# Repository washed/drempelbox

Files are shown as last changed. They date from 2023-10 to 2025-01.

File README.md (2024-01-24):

# drempelbox

kids friendly audio system

## Building

### Using cross

This project uses [cross](https://github.com/cross-rs/cross/) for compiling to different target architectures.
Cross requires a regular rust install via [rustup](https://rustup.rs/), docker or podman, and a Linux kernel mit binmft_misc support, see also [cross dependencies](https://github.com/cross-rs/cross/#dependencies).

Then install cross using cargo:
```bash
cargo install cross --git https://github.com/cross-rs/cross
```

To build for 64bit RaspberryPi OS (aarch64-unknown-linux-gnu), use
```bash
make build-aarch64-unknown-linux-gnu
```

To build for build-x86_64-unknown-linux-gnu, use
```bash
make build-aarch64-unknown-linux-gnu
```

Cross uses a containerized build environment to make cross compilation easy, install any
external dependencies for the build step in [Dockerfile.cross](Dockerfile.cross).
Docker [buildx](https://docs.docker.com/build/architecture/#install-buildx) is required for monitoring the build progress.

### Building directly on the host

You can also build this project directly on your host machine (for its architecture) using just cargo.
You will need to install the ALSA dev libs for your system, though (libasound2-dev on many platforms).

### Building on the RaspberryPi

***Don't do this unless you really need to! Compiling on the Zero 2W is very slow!***

To install the rust toolchain on the Zero 2W, you need to increase swap size.
From https://gist.github.com/tstellanova/0a6d8a70acc58a0d5be13ebaa7c935d4

```bash
sudo dphys-swapfile swapoff
sudo nano /etc/dphys-swapfile
```

Change `CONF_SWAPSIZE=100` to `CONF_SWAPSIZE=512` (or 1024)

```bash
sudo dphys-swapfile setup
sudo dphys-swapfile swapon
sudo reboot
```

Change to any swap size you feel appropriate for your needs.

## Running on RPi Zero 2W

Assuming a 64 bit RaspberryPI OS lite, install these packages to enable audio support:
- pipewire
- pipewire-alsa

Enable SPI for NFC ready support (using the raspi-config tool, for example).

Modify `/boot/firmware/config.txt`, adding this line at the end:
```
dtoverlay=gpio-poweroff,gpiopin=4,active_delay_ms=5000,inactive_delay_ms=1000,active_low=1
```
This enables the Pi to keep itself powered during normal operation
and switch itself off after poweroff. See the [schematic](#schematic) for details.

Create the service user and its group:
`sudo adduser --system --no-create-home --group drempelbox --uid 1337`

Add the user to these system groups to give it the necessary permissions:
```bash
sudo usermod -a -G gpio drempelbox
sudo usermod -a -G audio drempelbox
sudo usermod -a -G spi drempelbox
```

Create a polkit rule to allow the user to shutdown the system.
Create the file `/etc/polkit-1/rules.d/40-allow-shutdown.rules` and add these contents:
```
/* Allow members of the drempelbox group to shutdown without authentication */
polkit.addRule(function(action, subject) {
   if ( ( action.id == "org.freedesktop.login1.power-off" ||
          action.id == "org.freedesktop.login1.power-off-multiple-sessions"
        ) && subject.isInGroup("drempelbox") ) {
     polkit.log("Powering Off permitted for subject" + subject)
     return polkit.Result.YES;
   }
});
```

Restart the system or the polkit service for the changes to take effect:
```bash
systemctl restart polkit.service
```

## Hardware

Rough block diagram of system components:
```mermaid
classDiagram
    direction BT
    USB_PD_Decoy o-- Powerbank : USB A to USB C
    StepDownReg o-- USB_PD_Decoy : 12V
    5VFilter <|-- StepDownReg
    RPi <|-- 5VFilter : 5V micro USB
    RPi <|--|> NFC_Module : 5V, SPI
    USB_Soundcard *-- RPi : USB
    Amplifier <|-- USB_Soundcard : 3.5mm TRS
    Amplifier  o-- USB_PD_Decoy : 12V
    Speakers <|-- Amplifier

    class NFC_Module {
    }
    class RPi["RPi Zero 2W"] {
    }
    class USB_Soundcard["USB Soundcard"] {
    }
    class Powerbank{
        USB PD
        SoC Display
        USB C in/out
        USB Micro in
        USB A out
        charge()
        discharge()
    }
    class USB_PD_Decoy["USB PD Decoy"]{
        12V
    }
    class StepDownReg["5V DC/DC Buck"]{
        12V -> 5V
    }
    class 5VFilter["5V Filter"]
    class Amplifier{
    }
    class Speakers{
    }
```

### Schematic

KiCAD schematic

## Software

```mermaid
flowchart
    subgraph NTAG
        present{token presence changed?} -- no --> delay((delay)) --> present
        present -- added --> read[read token]
        present -- removed --> sendreq_ntag_stop[send player stop  request]
        read --> parse --> parse_ok
        parse_ok{is url?} -- yes --> sendreq_ntag_play[send player play request]
    end

    subgraph Player
        sendreq_ntag_stop --> stop{{stop all playback}}
        sendreq_ntag_play --> type{file or https}
        type -- file --> playfile{{stop spotify, play file}}
        type -- https --> isspotify{starts with 'open.spotify.com'?}
        isspotify -- no --> error
        isspotify -- yes --> playspotify{{stop file, play spotify}}
    end

    subgraph HTTP
        post_play[POST to play endpoint] --> query{has url query param?}
        query -- yes --> type
    end

```

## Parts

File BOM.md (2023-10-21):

# Bill of Materials

This list contains only the bigger BOM items as the rest (cables etc.) is very much in flux and will change a lot between versions.

| Item | Cost pp | Count | | Links |
| --- | --- | ----- | --- | --- |
| RPi Zero 2W | 20,00 | 1 | | [rasppishop](https://www.rasppishop.de/Raspberry-Pi-Zero-2-W) [berrybase](https://www.berrybase.de/raspberry-pi-zero-2-w) [welectron](https://www.welectron.com/Raspberry-Pi-Zero-2-W) |
| MicroSD card | ~ | 1 | | |
| micro USB otg -> USB A adapter | ~ | 1 | | |
| 40 pin RPi header | ~ | 1 | | |
| MFRC522 Module | 3,50 | 2 | | [amazon](https://amzn.eu/d/f9zHGjk) |
| USB soundcard | 7,99 | 1 | | [amazon](https://amzn.eu/d/9gCCpZK) |
| amplifier | 15,95 | 1 | | [soundimports](https://www.soundimports.eu/de/sure-electronics-aa-ab32231.html) |
| speaker chassis pair | 29,90 | 1 | | [soundimports](https://www.soundimports.eu/de/dayton-audio-dma45-4.html) |
| USB PD decoy | 4,35 | 2 | | [amazon](https://amzn.eu/d/6iVZGkV) |
| 5V step down | 6,95 | 2 | We _might_ need a bigger one | [pololu](https://www.pololu.com/product/2107) |
| Power bank | 16,99 | 2 | | [amazon](https://amzn.eu/d/ijY3aWm) |
| NFC tags | 0,33 | 40 | Anything [NTAG215](https://www.nxp.com/products/rfid-nfc/nfc-hf/ntag-for-tags-and-labels/ntag-213-215-216-nfc-forum-type-2-tag-compliant-ic-with-144-504-888-bytes-user-memory:NTAG213_2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) compatible should work | [amazon](https://amzn.eu/d/1htxMxP) |

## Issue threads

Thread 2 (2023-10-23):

Noisy Audio

washed, 2023-10-23:
The current setup emits a lot of audible noise from the speakers when both the RPi and the amp are powered from the same power source. Observed first in the prototype using the Pololu 5V DCDC converter for powering the Pi. The following lists the steps performed to debug this issue thus far.

* Assumed the noise originates from the DCDC converter
  * inserted LC filter between DCDC converter and RPi => **no change**
  *  powered pi from 5V rail of a clean lab power supply => **no change**
* Disconnected TRS audio cable between RPi and amp => **no noise (but obviously no audio, either)**
* Powering the RPi from a separate USB power supply, grounds probably disconnected (needs to be verified) => **clean audio!**

The last point indicates some issue with ground loops.

Next things to try:
* create star ground closer to the sound card/amp
* use shorter cables
* split grounds between sound card and amp
* check for ground loops in general

washed, 2023-10-28:
Mostly fixed by using the differential inputs (in fake diff mode because of the single end source). Some background noise remains and what is probably current ripple when using the 5V DCDC converter. The latter should still be addressed for the MVP imo.

tmh-alex, 2023-11-11:
There is the faintest background noise in my setup as well. I think it's really coming from the amp and I'm a bit 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.
Would've expected better performance from such a circuit.

But let's stay grounded (pun intended), it's really not a problem at all.

washed, 2023-11-12:
Yes I agree. Maybe after the MVP we could look for a lower power, lower noise alternative.

Meanwhile, give #16 a spin for a software approach to minimize experienced noise ;)

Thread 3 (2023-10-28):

Power on NFC

tmh-alex, 2023-10-28:
# What
If the Drempelbox is in standby, placing a tag on the reader wakes it up and starts playing right away.

# Why
Improved user experience with the user base "babies" in mind.

# Open questions
* How to poll the reader while in standby?
* What does standby mean? Raspi in low-energy state? Raspi turned off and power supply reacting on plugin signal?

washed, 2023-10-29:
This is super interesting.
Raspis don't really have low power states (like in ACPI compliant systems, for example). Afaik there is the `halt` state which shuts the OS down but keeps the bootcode in cache. The OS can be booted from this state via GPIO input. That might be one option. It will however be a mostly regular linux boot. Stuff like suspend to RAM does not exist for the Pi afaik.
A few options i could think of:
* keep the pi running, maybe try to shutdown cores or as much peripherals as possible, also keep the amp off and define this as our standby. NFC and the app (or a part of the app?) could keep running and watch the NFC reader.
* use a secondary MCU, also connected to the NFC reader, polling it regularly if the Pi is off. When it detects the presence of a token, boot the Pi and relinquish the SPI bus (tristate the pins). This could give us a bit more advanced power management stuff in general. Perhaps it will turn it, we need an extra MCU anyway. I hope not.
* in addition to the NFC reader, place a reed-relay, a magnetic or capacitive proximity sensor, or similar, where the presence of a figurine would trigger it, this could boot the Pi from aforementioned halt or off state

washed, 2023-10-30:
The simplest way would probably be the reed relay, which comes with the added benefit that it does not require power. It would mean we need a magnet in every figurine instead of in the base. Sure, we could also use an integrated, low force push button on the reader side, but to me this somehow breaks the very "non-mechanical" feel of the nfc interface. What do you think?

washed, 2023-10-31:
Reed relais were on sale at Reichelt and i needed some small bits and pieces anyway. I guess this is something we can start to work on when the MVP is done/close.

tmh-alex, 2023-11-01:
Certainly not an MVP thing. I don't like having mechanical components (other than the chassis, obviously) either, so let's focus on your [first two bullets](https://github.com/washed/drempelbox/issues/3#issuecomment-1784088492).

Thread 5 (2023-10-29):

Power on/off

washed, 2023-10-29:
After we have a possible, to be tested, solution in #11, we collect some additional stuff for discussion etc here. This thereby obsoletes #7.

washed, 2023-10-31:
See #11 for a possible solution.

washed, 2023-11-02:
I did some measurements to see if we have an issue here as described in https://github.com/washed/drempelbox/pull/11#pullrequestreview-1708477097.

### off
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
CH1: AMP_SD
CH2: AMP_SD_PI

### on
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
CH1: AMP_SD
CH2: AMP_SD_PI

### regular boot
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
CH1: AMP_SD
CH2: AMP_SD_PI
interesting blip there, maybe from GPIO configuration

### being rude and pulling the USB plug at the power bank
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
CH1: AMP_SD
CH2: AMP_SD_PI

### power bank turns on (pressing the button)
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
CH1: AMP_SD
CH2: VDD (12V rail)
note that we only see the ramp up from 5V to 12V here. Might need another capture, timing could also be interesting here. Very clean slope, though.

### power bank shuts off due to low current condition
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
CH1: AMP_SD
CH2: VDD (12V rail)

tmh-alex, 2023-11-11:
This all looks very promising as already mentioned on Signal, and if I'm not mistaken, your efforts already bore fruits to turn the box reliably off.
Then power-on part, on the other hand... :thinking: We have all sorts of ideas after the MVP, but a simple solution to start with?

washed, 2023-11-12:
The current circuit covers power on, in theory. I need to try it in practice. The idea was to rewire the button so it starts the power bank and the 5V supply. Shutdown via the same button should also be possible with another GPIO and some diodes.

washed, 2024-01-10:
Newest implementation in #15 should address all remaining issues we discovered in here.

Closed 2024-01-10.

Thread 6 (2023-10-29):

Assess power comsumption

washed, 2023-10-29:
I think we should have a rough idea which subsystems use what power in a few typical situations.
This would help us to optimize at the right place if we need to.

tmh-alex, 2023-10-29:
Setup
* raspi supplied by battery (optimistic **37 Wh** capacity)
* USB audio interface connected
* no user processes except ssh running (other than OS)

Results
* Battery lost **23 %** charge after **9.5 h** uptime
* Roughly **180 mA** average consumption

tmh-alex, 2023-10-29:
Good source for power saving possibilities on the raspi: https://raspberrypi.stackexchange.com/a/133854
The user also linked [this](https://learn.pi-supply.com/make/how-to-save-power-on-your-raspberry-pi/), [this](https://forums.raspberrypi.com/viewtopic.php?t=257144) and [this](https://blues.io/blog/tips-tricks-optimizing-raspberry-pi-power/) quite useful pages. Also proposed addon boards such as as [Sleepy Pi](https://spellfoundry.com/product/sleepy-pi/) and [Witty](https://www.uugear.com/product/witty-pi-3-realtime-clock-and-power-management-for-raspberry-pi/).

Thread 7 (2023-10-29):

Amp shutdown control

washed, 2023-10-29:
Some NPN BJT and a few resistors should do it, i think?
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

tmh-alex, 2023-10-29:
Works. Guess you could crank up R1, R2, and R5 by a magnitude of ten. Should still be robust enough against noise and reduced power consumption. I wonder if R2 is needed at all (defeats the floating property, doesn't it)?

washed, 2023-10-29:
Good points, thanks! That looks good as well:
* removed R2
* R1 to 10k
* R5 to 100k

Low level seems to be around 80mV; should be totally fine for a TTL input.
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

tmh-alex, 2023-10-29:
Waaait, aren't we overlooking the obvious? Is R5 even needed, either? According to the datasheet the base cutoff current is 50 nA, putting the upper limit of R1 to 52 MOhm. With 1 Mohm we'll surely be on the safe side with a base current of 2.6 mA. We can afford that :)

washed, 2023-10-29:
I have to admit i am super rusty (ha!) on discrete stuff. It seems fine without R5 and an R1 up to ~20k from some quick sim.

tmh-alex, 2023-10-29:
No worries, I learned and used this stuff at some point and I had to look at the diagram three times.

washed, 2023-10-29:
Used a BC547C (first NPN i found in a bag^) and a 100k between base and gpio. works a treat. One potential (pun intended) issue: we need to tie two previously separated grounds together. We'll need to see if this has any adverse effects; the schematic assumed both grounds are already the same net.

tmh-alex, 2023-10-29:
If that's a problem, try a 0.33 uF capacitor between the transistor base and the raspi ground. This should make a first order filter with the cutoff frequency at around 25 Hz (assuming R1=20 kOhm)

washed, 2023-10-29:
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

Much complex

washed, 2023-10-30:
Software side is implemented by this:
https://github.com/washed/drempelbox/commit/2e209eeeb605e9b5bdb4f3ad1ef7510ee3e0d448
we'll need to decide on when to switch on/off at some point. But now it is possible to do so :)

washed, 2023-10-31:
See #11 for an updated version of this

washed, 2023-11-02:
Happy with this after initial testing. Also see #11, #5.

Closed 2023-11-02.

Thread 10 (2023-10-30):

Cannot open ecad pdf and svg

tmh-alex, 2023-10-30:
Ecad [pdf](ecad/schematic.pdf) and [svg](ecad/schematic.svg) won't render/open on both my machine as well as in the repo landing page.

washed, 2023-10-30:
There where some screwed up versions initially. I force pushed over them, but i believe they stuck

washed, 2023-10-31:
@tmh-alex is this still broken for you?

tmh-alex, 2023-11-01:
It seems to be a Firefox problem, can open and download the files with Chromium no prob. First I thought it was thanks to the total Chrome dominance, but then I remembered that you're using FF, too...

washed, 2023-11-02:
I'm using chromium for private stuff on my laptop. I'll try with Firefox to see if I can reproduce this.

washed, 2023-11-02:
Works on Firefox just fine for me. Using Firefox 119.

tmh-alex, 2023-11-11:
Nargh, I missed to whitelist one domain in NoScript. Problem solved.

Closed 2023-11-11.

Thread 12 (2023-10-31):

Repo structure

washed, 2023-10-31:
We now have software, documentation, schematics etc in this repo.
Do we want to restructure the repo a bit to make it easier to find stuff?
A first good step might be to put all of the software pieces into their own subfolder?

Something like:
* root
  * ecad
  * app
  * mcad

tmh-alex, 2023-11-01:
The project is small enough that I have no feelings whatsoever about it's current structure. But it's probably a good idea in the long run!

To expand your proposal a bit, is that where you're heading?
* /
  * app/
    * audio/
    * ...
    * src/
    * Docker stuff
    * Makefile
    * Rust stuff
    * ...
  * ecad/
  * mcad/

washed, 2023-11-01:
zeah something like that. But we can also leave it like it is for now

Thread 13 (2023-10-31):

Read power bank SOC

washed, 2023-10-31:
Maybe somewhat unnecessary, but i was thinking if we should read the power banks soc display to get this state into our application. This would allow us to do a few interesting things like
* warn when we are running out battery (playing a sound or something)
* performing a clean shutdown before the battery dies
* just do it because it's fancy

"worst case" would be to use a shift register to get the led states.

tmh-alex, 2023-11-01:
[chimes, Majel Barrett's voice] Warning, core at 5 %. Emergency shutdown imminent.

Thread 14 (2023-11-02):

Volume Control UI

washed, 2023-11-02:
We already decided on using push buttons for controlling volume. One for volume up, one for volume down. We should start to think about how we want to integrate this into our case design (which we also still need to do).
Any bright ideas?

tmh-alex, 2023-11-11:
Following your philosophy of minimizing moving parts, how about capacitive touch sensors? E.g., https://www.adafruit.com/product/1362. We could use something as simple as screwheads as the touch interface (though i'd prefer something prettier).

washed, 2023-11-12:
I also thought about touch, it would be elegant for sure. Maybe some nicely finished and inset stainless steel bolts. However, i am unsure how well touch works for little kids. I could imagine that haptic feedback might be really useful. What do you think?

tmh-alex, 2023-11-12:
Have you got an old rumble gamepad lying around perhaps? Best of both worlds 8)

But seriously, you've got a point there. Some very sturdy rubber some would be child-friendly?

washed, 2023-11-12:
I was thinking about vibration as well... might be interesting post MVP. I also briefly thought about mild electric shocks, but i somehow think this won't fly :imp:
Originally i thought about a regular super cheap push button with some wooden actuator on top that's held in place with some tape or a rubber gasket.

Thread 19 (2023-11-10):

librespot channel closed error

tmh-alex, 2023-11-10:
Got this spurious error:
```
Nov 10 23:40:41 toniblaster drempelbox[1365]: 2023-11-10T22:40:41.859773Z  INFO drempelbox::player: playing spotify from url log_url="https://open.spotify.com/track/4abJbqX8C8CQTXHZxEbJZz?si=f04b62b8e85c4bf1"
Nov 10 23:40:41 toniblaster drempelbox[1365]: Playing...
Nov 10 23:40:41 toniblaster drempelbox[1365]: 2023-11-10T22:40:41.859864Z ERROR librespot_playback::player: Player Commands Error: channel closed
Nov 10 23:40:41 toniblaster drempelbox[1365]: 2023-11-10T22:40:41.864665Z DEBUG hyper::proto::h1::conn: read eof
Nov 10 23:40:47 toniblaster drempelbox[1365]: 2023-11-10T22:40:47.289095Z DEBUG hyper::proto::h1::io: parsed 3 headers
Nov 10 23:40:47 toniblaster drempelbox[1365]: 2023-11-10T22:40:47.289181Z DEBUG hyper::proto::h1::conn: incoming body is empty
Nov 10 23:40:47 toniblaster drempelbox[1365]: 2023-11-10T22:40:47.289273Z  INFO drempelbox::server: Got stop request
Nov 10 23:40:47 toniblaster drempelbox[1365]: 2023-11-10T22:40:47.289313Z  INFO drempelbox::server: submitted stop request
Nov 10 23:40:47 toniblaster drempelbox[1365]: 2023-11-10T22:40:47.289455Z DEBUG hyper::proto::h1::io: flushed 75 bytes
Nov 10 23:40:47 toniblaster drempelbox[1365]: 2023-11-10T22:40:47.289497Z  INFO drempelbox::player: received stop request
Nov 10 23:40:47 toniblaster drempelbox[1365]: 2023-11-10T22:40:47.289542Z  INFO drempelbox::spotify_player: stopping spotify
Nov 10 23:40:47 toniblaster drempelbox[1365]: 2023-11-10T22:40:47.289586Z ERROR librespot_playback::player: Player Commands Error: channel closed
Nov 10 23:40:47 toniblaster drempelbox[1365]: 2023-11-10T22:40:47.297705Z DEBUG hyper::proto::h1::conn: read eof
```
Couldn't repeat it. The steps that came before this error as far as I can remember:
1. `make track`
2. `make stop`
3. A few more times 1 and 2
4. `make volume_up` a couple of times while player was stopped

washed, 2023-11-11:
Looks like the entire player task died. We will need some sort of watchdog thingy for all of those long running tasks anyhow. I'll think about it. Same for the file player to make sure the sink is still running, the web server is still running etc...

I think the hyper logs are unrelated.

washed, 2023-11-11:
Ah, do you have logs before the ones you posted? Ideally from the start of the app until you saw the failure? Even the first play request in the logs you posted seems to have failed.

tmh-alex, 2023-11-11:
I'm starting to like journalctl. It's even possible to get the logs for a particular boot session. Here're the complete logs for the drempelbox process, tell me if you need all the logs (including kernel messages perhaps?).

washed, 2023-11-12:
Awesome, thanks! Looks to me like the spotify player crashed somewhere inside librespot and took the bigger player thread down with it:
```
Nov 10 23:39:57 toniblaster drempelbox[1365]: 2023-11-10T22:39:57.022170Z  INFO drempelbox::server: Got URL request url="https://open.spotify.com/track/4abJbqX8C8CQTXHZxEbJZz?si=f04b62b8e85c4bf1"
Nov 10 23:39:57 toniblaster drempelbox[1365]: 2023-11-10T22:39:57.022264Z  INFO drempelbox::server: submitted URL request
Nov 10 23:39:57 toniblaster drempelbox[1365]: 2023-11-10T22:39:57.022463Z  INFO drempelbox::player: received URL player request log_url="https://open.spotify.com/track/4abJbqX8C8CQTXHZxEbJZz?si=f04b62b8e85c4bf1"
Nov 10 23:39:57 toniblaster drempelbox[1365]: 2023-11-10T22:39:57.022507Z  INFO drempelbox::player: playing spotify from url log_url="https://open.spotify.com/track/4abJbqX8C8CQTXHZxEbJZz?si=f04b62b8e85c4bf1"
Nov 10 23:39:57 toniblaster drempelbox[1365]: Playing...
Nov 10 23:39:57 toniblaster drempelbox[1365]: 2023-11-10T22:39:57.022675Z DEBUG librespot_playback::player: command=Load(SpotifyId { id: 181874502310399482585459847615985601637, audio_type: Track }, true, 0)
Nov 10 23:39:57 toniblaster drempelbox[1365]: 2023-11-10T22:39:57.028615Z DEBUG hyper::proto::h1::conn: read eof
Nov 10 23:39:57 toniblaster drempelbox[1365]: 2023-11-10T22:39:57.051347Z DEBUG librespot_core::session: Invalidating session[0]
Nov 10 23:39:57 toniblaster drempelbox[1365]: 2023-11-10T22:39:57.051520Z ERROR librespot_playback::player: Unable to load audio item: MercuryError
Nov 10 23:39:57 toniblaster drempelbox[1365]: 2023-11-10T22:39:57.051954Z ERROR librespot_playback::player: Unable to load audio item: MercuryError
Nov 10 23:39:57 toniblaster drempelbox[1365]: 2023-11-10T22:39:57.052092Z  WARN librespot_playback::player: Skipping to next track, unable to load track <SpotifyId { id: 181874502310399482585459847615985601637, audio_type: Track }>: ()
Nov 10 23:39:57 toniblaster drempelbox[1365]: 2023-11-10T22:39:57.052181Z DEBUG librespot_playback::player: drop PlayerInternal[0]
Nov 10 23:39:57 toniblaster drempelbox[1365]: 2023-11-10T22:39:57.052258Z  INFO drempelbox::spotify_player: EndOfTrack!
Nov 10 23:39:57 toniblaster drempelbox[1365]: 2023-11-10T22:39:57.052461Z DEBUG librespot_core::session: drop Dispatch
Nov 10 23:39:57 toniblaster drempelbox[1365]: 2023-11-10T22:39:57.052622Z ERROR librespot_core::session: Connection reset by peer (os error 104)
Nov 10 23:39:57 toniblaster drempelbox[1365]: 2023-11-10T22:39:57.059097Z DEBUG librespot_playback::player: PlayerInternal thread finished.
Nov 10 23:40:01 toniblaster drempelbox[1365]: 2023-11-10T22:40:01.002751Z  INFO drempelbox::server: Got stop request
Nov 10 23:40:01 toniblaster drempelbox[1365]: 2023-11-10T22:40:01.002791Z  INFO drempelbox::server: submitted stop request
Nov 10 23:40:01 toniblaster drempelbox[1365]: 2023-11-10T22:40:01.003253Z  INFO drempelbox::player: received stop request
Nov 10 23:40:01 toniblaster drempelbox[1365]: 2023-11-10T22:40:01.003294Z  INFO drempelbox::spotify_player: stopping spotify
Nov 10 23:40:01 toniblaster drempelbox[1365]: 2023-11-10T22:40:01.003329Z ERROR librespot_playback::player: Player Commands Error: channel closed
```

Might just have been a network glitch, this line points me to that idea:
`Nov 10 23:39:57 toniblaster drempelbox[1365]: 2023-11-10T22:39:57.052622Z ERROR librespot_core::session: Connection reset by peer (os error 104)`

We should probably be more resilient about underlying pieces crashing and restart them if necessary. If you have an idea to repro this easily, we could start working and testing a fix/improvement.

washed, 2023-11-12:
Looking at it more closely, our tasks where running just fine, but the librespot internal player died.

washed, 2024-01-12:
From playing with the service file I think i now know what happened here. When you saw this, we still had a broken service definition and the service started before all the dependencies where up, specifically the actually executing user service and the sound device. I have seen the exact same behavior when i was executing the service with the new drempelbox user, but hadn't adjusted the `Required` and `After` statements. So I'd like to park this as "probably fixed" for now. If it comes up again, we can revisit!

tmh-alex, 2025-02-02:
Didn't observe that issue anymore, either. Let's close it?

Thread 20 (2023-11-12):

Dedicated drempelbox user

washed, 2023-11-12:
This is a follow-up issue from #18.

We currently run the service as whatever user is being used for ssh'ing into the Pi and registering the service.
It might be helpful to set up a dedicated user and perhaps a group along with it to have for the application with just the permissions it needs and nothing more.

For development and even a bit beyond, the current solution is probably ok.

tmh-alex, 2024-01-08:
Agreed.

washed, 2024-01-10:
Implemented by #15

Closed 2024-01-10.

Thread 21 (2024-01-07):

Use volume buttons for skipping tracks

tmh-alex, 2024-01-07:
Since we don't (yet) have an acceleration sensor like the Tonibox, we could use the volume buttons to skip through tracks. Short press louder/quieter, long press skip forward/backward.

I'd like to take that as an opportunity to finally code some Rust.

washed, 2024-01-07:
Sounds great! Do you wanna do the basic volume button implementation as well?

Hint: we are using rppal for GPIOs

tmh-alex, 2024-01-08:
Sure! Created #22 to cover the task.

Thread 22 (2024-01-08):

Volume button support

tmh-alex, 2024-01-08:
We decided on NO hardware volume buttons that now need support.

Just like #21, I'd like to take this task to code get into Rust coding.

washed, 2024-01-08:
Took me a second to parse "normally open" correctly :)

tmh-alex, 2024-01-08:
Took me a second to parse what you mean and then it was so blatantly obvious, haha

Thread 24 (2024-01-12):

Use interrupts for reading GPIOs

washed, 2024-01-12:
Currently we are using simple polling to get the status of input pins (Pi shutdown only, but volume control will also need to read inputs). Unless it's terribly hard to do so, it would be really nice to use interrupts to read inputs! It would improve reaction time and safe on CPU time as well. Also, I like interrupts.

tmh-alex, 2024-01-16:
I like interrupts, too.

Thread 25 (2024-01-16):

Multi-box support

tmh-alex, 2024-01-16:
When two or more Drempelboxes are present in the same network, all should play simultaneously from the same (cloud) source. The latest Drempel put on any box' sensor determines the stream for all boxes.

Optional: Roon support.

washed, 2024-01-16:
Oof, sub millisecond sync with a regular Linux machine? Not saying it's impossible, but sure ain't easy.

washed, 2024-01-17:
I'm wondering if we can get away with synchronizing chunks of audio with timestamps and making sure our system times are synched _well enough_ (TBD). This would also allow a lagging box to catch up.

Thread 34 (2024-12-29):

Current state of affairs on my end

tmh-alex, 2024-12-29:
# The good
* Built up the whole circuit according to our schematic
* Added an LED as a status light to my board (changes to the schematic yet to come)
* Keepalive works fine at the press of the single-push-double-throw (SPDT)  button
* Supply switches gently off after calling `sudo shutdown now`
* Service file runs, can see continuous debug statements from the program

# The bad
* Circuit not powering off at the push of the SPDT button
* ~~`make track` etc. not working, says "could not connect to server" despite `CURL_TEST_HOST_PORT` having (I believe) the right hostname/IP and port (default 3000)~~
  * This was apparently due to Spotify stalling a couple of setup steps like port binding. Once I connected to the Drempelbox instance from my Android Spotify everything worked.
* I should make myself more familiar with what's already implemented:
  * ~~Amp circuit currently not coming alive (should this happen only when starting a new track?)~~
    * Ground connection was missing.
  * State of the shutdown functionality

# The ugly
* :exclamation: NEW: Still noisy as hell :sob:
* The assembly with all its wires connected via pinheads and some loose components is rather brittle, it won't survive long in the hands of a toddler
  * I broke one of the volume buttons in the meanwhile
* Also, everything is really cramped, making it really difficult to find errors and not causing new ones by accident in the process. I'm really fond of your idea for designing a proper PCB...

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

# The silver lining
* We're like ~~98~~ 95 % there, the remaining ~~two~~ five might be a hassle but aren't impossible! :muscle:

tmh-alex, 2025-01-05:
I think I know why my raspi seemingly died a few times in the past and it had to be set up from scratch again. It ran out of memory due to RaspiOS' default logging setting `auto`, which writes all logs including every stupid debug statement to disk. Set it to `volatile` now, let's see what happens.

tmh-alex, 2025-01-06:
Box works now except for shutdown on the push of the SPDT button. But it's noisy as hell... I thiiink it's the line between the audio adapter and the amp

tmh-alex, 2025-01-07:
Did some more investigations today.

### Noise issue
* Confirmed a previous observation from last year just to be sure: No audible noise on the USB adapter output, tried with headphones → adapter not to blame.
* Pulled the audio cable out and made sure I don't have loops around supply lines etc. Noise level is now back to the level of my original experimental setup. Shielding the cable with grounded aluminium foil didn't bring any change → Ground loop. I wonder if the digital GND is really separate or I accidentally short-circuited it again.

### Other
* Shutdown not working: Probably due to a mistake in the layout because I checked both SPDT button terminal pairs positively for their functionality.
* Amp not shutting down after stopping a song: Also just a layout mistake. I manually connected the amp's SD pin to GND, it went dead silent.
* NEW: USB-C extension cord between battery and terminal on the outside of the box is polarized (I now learned that these things are not part of the USB-C spec), orientation of the charging cable matters as a consequence.

washed, 2025-01-08:
Okay there's a lot in this single issue^^.

- Does the shutdown work when you manually pull the input to ground?
  - TBH, i don't 100% remember the state of this feature. I know there was still something i wasn't happy about wrt systemd integration
- About the USB-C extension: yes they aren't part of the spec, but if they are just dumb extensions and have all pins connected it should work in both orientations (for simple use cases). But I guess you are saying our extension only connects one half of pins?
- What are the 4 inductors (?) doing on your board?

washed, 2025-01-08:
Oh also about shutdown: did you create the polkit rules as outlined in the readme?

tmh-alex, 2025-01-08:
Thanks for the response Marc!

* Single issue: Was meant as a summary to both you and me, otherwise, I forget what part to take a look at next...
* Shutdown: Yes, it does shut down properly when manually connected to ground.
* USB-C extension and orientation: I thought it was just a dumb cable, but there seems to be more to it. I have the same issue with my laptop docking station and the extension cord I'm using there. Need to read up on the C spec, pin layout, pulldown resistors for communicating orientation, and whatnot.
* Inductor array: One inductor is 330 uH, needed a couple to get close to the design value of 1.5 mH. Probably wouldn't make a difference anyway, but I had both the parts and the space.
* Polkit rule: Yes, even added my own user to it so I can test easily if shutdown works without being root.

washed, 2025-01-08:
Are you sure the button you are using has two isolated contactors?

washed, 2025-01-09:
OR -> the button in fact doesn't have isolated contactors and thus couples the two grounds directly.

tmh-alex, 2025-01-10:
I don't have much choice in parts, I got three bags of assorted stuff for resistors, inductors and capacitors from which I have to assemble the desired values.

As for the button, I'll check the grounds. But in all likelihood, I made a mistake in the layout as I did with the amp supply. :zany_face:

tmh-alex, 2025-01-12:
Dis- and reassembled the box to day to do some investigations:
* Shutdown: Works now, it was indeed a missing ground connection as suspected.
* Digital ground: Completely behind the inductors, proved by removing one of the four series inductances to break the circuit.
* Noise: Still there, bending and moving the wires has influence on noise levels.
Box is up and running again. With amp shutdown when the stop signal is sent it won't bother me for now. Btw, the box idles with the amp powered and the amp shutdown pin floating. Don't know yet if this is expected behaviour.

tmh-alex, 2025-01-13:
I forgot to have a look at the shutdown circuit yesterday. Good news, it's also fixed now! I just had the base of transitor Q1 (the one that pulls AMP_SD to ground or leaves it floating) permanently connected to ground. One of the many issue resulting from my sloppiness when working prototyping boards that have their lanes all the way from one end to the other...

The noise, however, is still there when playing tracks. I will close this issue and open a new one one with a more limited scope. ;-)

tmh-alex, 2025-01-16:
Noise gone thanks to @washed's simple 1.5 mH coil in place of my storage chokes. 💪 Fwiw, the simple coil has about 10 Ohms resistance.

Closed 2025-01-16.

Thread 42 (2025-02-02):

Observations after ten days with the kid

tmh-alex, 2025-02-02:
Just fyi @washed

# User Experience

## Good
* It exists at all and the kid has a new toy that it likes to play with (=dance to)!
* Tonibox-like magnetic tag/figure catching works like a charm. After a few attempts, the kid has no issues finding the rights spot.
* Status light a huge plus, glad I decided last minute to put it in. The kid understands that the box is not ready when it's dark.
* Fabric cover makes the kid focus on the intended function of the box. When removed, all the different buttons and plugs and hinges and whatnot become interesting.

## Bad
* Sometimes, the box takes no more commands or just keeps playing. Confuses the kid as there is no indicator why things aren't working as intended.
* Volume buttons are too slippery and hard to press, the kid sometimes fails to push in a controlled manner. And then there's the questionable looks when covered in cloth.
* Status light does not provide feedback over startup or shutdown process. Confusing to both the kid and the parents.
* Fabric cover used for grabbing and transporting the box as a whole.

# Software & Hardware

## Good
* Didn't experience one hickup where the application wouldn't come up properly. Port binding etc. all working reliably.
* Additional capacitance in the Pi's power supply fixed issue with USB audio adapter.
* Sound and volume pretty alright also for the box's future as a general BT speaker.
* Alright battery life already, would estimate at least 5 hours of continuous music playing.

## Bad
* Biggest bummer so far: Box just stops working after some time (see above) and, at the first glance, I couldn't see any reason in the logs why.

# Next Steps
* Will put arcade-style buttons in place of the existing ones
* Will do some more digging on the box-stops-working issue before opening a dedicated issue

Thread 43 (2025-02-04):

ALSA module fails to initialize on first application start

tmh-alex, 2025-02-04:
The ALSA module failes to initialize on first application start. Subsequent runs are fine. Went unnoticed because the service is set to always restart.

```
Feb 03 21:57:15 toniblaster systemd[1]: Started drempelbox.service - drempelbox.
Feb 03 21:57:16 toniblaster drempelbox[523]: thread 'main' panicked at src/alsa.rs:31:14:
Feb 03 21:57:16 toniblaster drempelbox[523]: Failed to find mixer control.
Feb 03 21:57:16 toniblaster drempelbox[523]: stack backtrace:
Feb 03 21:57:16 toniblaster drempelbox[523]:    0:       0x5572bbf640 - <std::sys::backtrace::BacktraceLock::print::DisplayBacktrace as core::fmt::Display>::fmt::hb96435122ab7425b
Feb 03 21:57:16 toniblaster drempelbox[523]:    1:       0x5572be6140 - core::fmt::write::h7c561ca7c8433f95
Feb 03 21:57:16 toniblaster drempelbox[523]:    2:       0x5572bbb08c - std::io::Write::write_fmt::hf7d9a5a24b8e20d9
Feb 03 21:57:16 toniblaster drempelbox[523]:    3:       0x5572bc09e4 - std::panicking::default_hook::{{closure}}::hede73113e98cf4b8
Feb 03 21:57:16 toniblaster drempelbox[523]:    4:       0x5572bc054c - std::panicking::default_hook::he405b118d658ffce
Feb 03 21:57:16 toniblaster drempelbox[523]:    5:       0x5572bc11d8 - std::panicking::rust_panic_with_hook::hd458a5a67c8fc44a
Feb 03 21:57:16 toniblaster drempelbox[523]:    6:       0x5572bc0eb0 - std::panicking::begin_panic_handler::{{closure}}::h4b3f096abbb4f13c
Feb 03 21:57:16 toniblaster drempelbox[523]:    7:       0x5572bbfb3c - std::sys::backtrace::__rust_end_short_backtrace::hf33da5adf3f15f28
Feb 03 21:57:16 toniblaster drempelbox[523]:    8:       0x5572bc0b80 - rust_begin_unwind
Feb 03 21:57:16 toniblaster drempelbox[523]:    9:       0x55722f837c - core::panicking::panic_fmt::hbb2cf5b22d399018
Feb 03 21:57:16 toniblaster drempelbox[523]:   10:       0x55722f834c - core::option::expect_failed::h61181b2b040c1333
Feb 03 21:57:16 toniblaster drempelbox[523]:   11:       0x557236856c - drempelbox::main::{{closure}}::hb517108b27b54caa
Feb 03 21:57:16 toniblaster drempelbox[523]:   12:       0x557235f87c - tokio::runtime::park::CachedParkThread::block_on::h327fbb4f0a2e6796
Feb 03 21:57:16 toniblaster drempelbox[523]:   13:       0x557237e77c - drempelbox::main::h5bab3e1ca5f0444a
Feb 03 21:57:16 toniblaster drempelbox[523]:   14:       0x557236c0a8 - std::sys::backtrace::__rust_begin_short_backtrace::hf684f39cef0ebd36
Feb 03 21:57:16 toniblaster drempelbox[523]:   15:       0x55723d0d80 - std::rt::lang_start::{{closure}}::h6bcd3928ae43a6ee
Feb 03 21:57:16 toniblaster drempelbox[523]:   16:       0x5572bb30e4 - std::rt::lang_start_internal::h61a6df977a78ceb9
Feb 03 21:57:16 toniblaster drempelbox[523]:   17:       0x557237ea14 - main
Feb 03 21:57:17 toniblaster drempelbox[523]:   18:       0x7f88c07740 - __libc_start_call_main
Feb 03 21:57:17 toniblaster drempelbox[523]:                                at ./csu/../sysdeps/nptl/libc_start_call_main.h:58:16
Feb 03 21:57:17 toniblaster drempelbox[523]:   19:       0x7f88c07818 - __libc_start_main_impl
Feb 03 21:57:17 toniblaster drempelbox[523]:                                at ./csu/../csu/libc-start.c:360:3
Feb 03 21:57:17 toniblaster drempelbox[523]:   20:       0x55722f8ab4 - <unknown>
Feb 03 21:57:17 toniblaster systemd[1]: drempelbox.service: Main process exited, code=exited, status=101/n/a
Feb 03 21:57:17 toniblaster systemd[1]: drempelbox.service: Failed with result 'exit-code'.
Feb 03 21:57:22 toniblaster systemd[1]: drempelbox.service: Scheduled restart job, restart counter is at 1.
Feb 03 21:57:22 toniblaster systemd[1]: Stopped drempelbox.service - drempelbox.
Feb 03 21:57:22 toniblaster systemd[1]: Started drempelbox.service - drempelbox.
Feb 03 21:57:22 toniblaster drempelbox[608]: 2025-02-03T20:57:22.421819Z DEBUG drempelbox::alsa: Setting volume to 52428 of range 0 - 65536.
Feb 03 21:57:22 toniblaster drempelbox[608]: 2025-02-03T20:57:22.464075Z DEBUG drempelbox::shutdown: shutdown task started
Feb 03 21:57:22 toniblaster drempelbox[608]: 2025-02-03T20:57:22.464048Z  INFO drempelbox::button: button poll task on pin InputPin { pin: Pin { pin: 17, gpio_state: EventLoop { gpio_mem: GpioMem { mem_ptr: 0x7fbc>
Feb 03 21:57:22 toniblaster drempelbox[608]: 2025-02-03T20:57:22.464048Z  INFO drempelbox::button: button poll task on pin InputPin { pin: Pin { pin: 27, gpio_state: EventLoop { gpio_mem: GpioMem { mem_ptr: 0x7fbc>
Feb 03 21:57:22 toniblaster drempelbox[608]: 2025-02-03T20:57:22.574732Z  INFO drempelbox::spotify_player: using cached credentials
Feb 03 21:57:23 toniblaster drempelbox[608]: 2025-02-03T20:57:23.005250Z  WARN librespot_core::apresolve: Failed to resolve all access points, using fallbacks
Feb 03 21:57:23 toniblaster drempelbox[608]: 2025-02-03T20:57:23.005310Z  WARN librespot_core::apresolve: Resolve access points error: Service unavailable { client error (Connect) }
Feb 03 21:57:23 toniblaster drempelbox[608]: 2025-02-03T20:57:23.386988Z  INFO drempelbox::ntag: Starting NTAG reader...
Feb 03 21:57:23 toniblaster drempelbox[608]: 2025-02-03T20:57:23.392309Z  INFO drempelbox::ntag215: MFRC522 version version=146
Feb 03 21:57:23 toniblaster drempelbox[608]: 2025-02-03T20:57:23.392669Z DEBUG drempelbox::amp: submitted amp power on request
Feb 03 21:57:23 toniblaster drempelbox[608]: 2025-02-03T20:57:23.392788Z  INFO drempelbox::server: Starting http server...
Feb 03 21:57:23 toniblaster drempelbox[608]: 2025-02-03T20:57:23.644423Z DEBUG drempelbox::led: submitted amp LED on request
Feb 03 21:57:32 toniblaster drempelbox[608]: 2025-02-03T20:57:32.102551Z  INFO drempelbox::ntag: new token: [04, 90, 78, 69, ff, 61, 80]
Feb 03 21:57:32 toniblaster drempelbox[608]: 2025-02-03T20:57:32.845652Z DEBUG drempelbox::ndef: got byte 03
Feb 03 21:57:32 toniblaster drempelbox[608]: 2025-02-03T20:57:32.845714Z DEBUG drempelbox::ndef: message_init=3
Feb 03 21:57:32 toniblaster drempelbox[608]: 2025-02-03T20:57:32.845734Z DEBUG drempelbox::ndef: got byte 4c
Feb 03 21:57:32 toniblaster drempelbox[608]: 2025-02-03T20:57:32.845751Z DEBUG drempelbox::ndef: message_len=76
Feb 03 21:57:32 toniblaster drempelbox[608]: 2025-02-03T20:57:32.845767Z DEBUG drempelbox::ndef: got byte d1
Feb 03 21:57:32 toniblaster drempelbox[608]: 2025-02-03T20:57:32.845781Z DEBUG drempelbox::ndef: got byte 01
Feb 03 21:57:32 toniblaster drempelbox[608]: 2025-02-03T20:57:32.845797Z DEBUG drempelbox::ndef: got byte 48
Feb 03 21:57:32 toniblaster drempelbox[608]: 2025-02-03T20:57:32.845813Z DEBUG drempelbox::ndef: got bytes [55]
Feb 03 21:57:32 toniblaster drempelbox[608]: 2025-02-03T20:57:32.845831Z DEBUG drempelbox::ndef: got bytes [04, 6f, 70, 65, 6e, 2e, 73, 70, 6f, 74, 69, 66, 79, 2e, 63, 6f, 6d, 2f, 74, 72, 61, 63, 6b, 2f, 36, 7a, 4>
Feb 03 21:57:32 toniblaster drempelbox[608]: 2025-02-03T20:57:32.846304Z  INFO drempelbox::player: received URL player request log_url="https://open.spotify.com/track/6zHr40EcGxX2nWKG0Z6dkk?si=2jNIAEneQc293aaOLHRm>
Feb 03 21:57:32 toniblaster drempelbox[608]: 2025-02-03T20:57:32.846352Z  INFO drempelbox::player: playing spotify from url log_url="https://open.spotify.com/track/6zHr40EcGxX2nWKG0Z6dkk?si=2jNIAEneQc293aaOLHRmOQ"
Feb 03 21:57:32 toniblaster drempelbox[608]: 2025-02-03T20:57:32.846378Z DEBUG drempelbox::amp: submitted amp on request
Feb 03 21:57:32 toniblaster drempelbox[608]: Playing...
Feb 03 21:57:32 toniblaster drempelbox[608]: 2025-02-03T20:57:32.907414Z  WARN librespot_core::apresolve: Failed to resolve all access points, using fallbacks
Feb 03 21:57:32 toniblaster drempelbox[608]: 2025-02-03T20:57:32.907497Z  WARN librespot_core::apresolve: Resolve access points error: Service unavailable { client error (Connect) }
Feb 04 08:19:05 toniblaster drempelbox[608]: 2025-02-04T07:19:05.887452Z  INFO drempelbox::ntag: token removed: [04, 90, 78, 69, ff, 61, 80]
Feb 04 08:19:05 toniblaster drempelbox[608]: 2025-02-04T07:19:05.887608Z  INFO drempelbox::player: received stop request
Feb 04 08:19:05 toniblaster drempelbox[608]: 2025-02-04T07:19:05.887670Z DEBUG drempelbox::amp: submitted amp off request
Feb 04 08:19:05 toniblaster drempelbox[608]: 2025-02-04T07:19:05.887744Z  INFO drempelbox::spotify_player: stopping spotify
```

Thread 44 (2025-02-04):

Application sometimes freezes

tmh-alex, 2025-02-04:
The application sometimes freezes. May happen before the first song even played or after many hours. Won't read new tags or see an existing one disappear, volume buttons don't have an effect and produce no log output, already running songs would keep playing until the end (don't know about the behaviour of playlists). The raspi itself remains responsive and can be reached via ssh.

In the following are the last 5 lines of the drempelbox unit logs for three different crashes.

```
Jan 26 09:20:46 toniblaster drempelbox[607]: 2025-01-26T08:20:46.993013Z  INFO drempelbox::ntag215: MFRC522 version version=146
Jan 26 09:20:46 toniblaster drempelbox[607]: 2025-01-26T08:20:46.993293Z DEBUG drempelbox::amp: submitted amp power on request
Jan 26 09:20:46 toniblaster drempelbox[607]: 2025-01-26T08:20:46.993737Z  INFO drempelbox::server: Starting http server...
Jan 26 09:20:47 toniblaster drempelbox[607]: 2025-01-26T08:20:47.245429Z DEBUG drempelbox::led: submitted amp LED on request
Jan 26 09:21:00 toniblaster drempelbox[607]: 2025-01-26T08:21:00.338818Z ERROR drempelbox::ntag215: error in SPI comms: IncompleteFrame
```

```
Jan 26 10:52:29 toniblaster drempelbox[744]: 2025-01-26T09:52:29.277768Z  INFO drempelbox::player: playing spotify from url log_url="https://open.spotify.com/track/4S1vA0mTayFbnHrwdkzPWT?si=x0xQratgREGxo19ivfn6DA"
Jan 26 10:52:29 toniblaster drempelbox[744]: 2025-01-26T09:52:29.277800Z DEBUG drempelbox::amp: submitted amp on request
Jan 26 10:52:29 toniblaster drempelbox[744]: Playing...
Jan 26 10:52:29 toniblaster drempelbox[744]: 2025-01-26T09:52:29.312126Z  WARN librespot_core::apresolve: Failed to resolve all access points, using fallbacks
Jan 26 10:52:29 toniblaster drempelbox[744]: 2025-01-26T09:52:29.312206Z  WARN librespot_core::apresolve: Resolve access points error: Service unavailable { client error (Connect) }
```

```
Feb 01 07:13:58 toniblaster drempelbox[607]: 2025-02-01T06:13:58.286483Z DEBUG drempelbox::ndef: got bytes [55]
Feb 01 07:13:58 toniblaster drempelbox[607]: 2025-02-01T06:13:58.286499Z DEBUG drempelbox::ndef: got bytes [04, 6f, 70, 65, 6e, 2e, 73, 70, 6f, 74, 69, 66, 79, 2e, 63, 6f, 6d, 2f, 74, 72, 61, 63, 6b, 2f, 33, 63, 4a, 53, 4a, 54, 72, 45, 4b, 4e, 66, 6d, 31, 54, 6d, 6f, 73, 77, 45, 72, 6b, 57, 3f, 73, 69, 3d, 61, 33, 75, 74, 48, 71, 71, 79, 52, 67, 57, 45, 47, 43, 73, 64, 42, 44, 47, 7a, 50, 67]
Feb 01 07:13:58 toniblaster drempelbox[607]: 2025-02-01T06:13:58.286713Z  INFO drempelbox::player: received URL player request log_url="https://open.spotify.com/track/3cJSJTrEKNfm1TmoswErkW?si=a3utHqqyRgWEGCsdBDGzPg"
Feb 01 07:13:58 toniblaster drempelbox[607]: 2025-02-01T06:13:58.286747Z  INFO drempelbox::player: playing spotify from url log_url="https://open.spotify.com/track/3cJSJTrEKNfm1TmoswErkW?si=a3utHqqyRgWEGCsdBDGzPg"
Feb 01 07:13:58 toniblaster drempelbox[607]: 2025-02-01T06:13:58.286771Z DEBUG drempelbox::amp: submitted amp on request
Feb 01 07:13:58 toniblaster drempelbox[607]: Playing...
```

I trapped the `IncompleteFrame` error just like the `TimeoutError` (see #40) but cannot tell if that changed anything about the frequency of the freezes. That is, I don't know if it's one possible cause.

tmh-alex, 2025-02-04:
@washed Is there a way to get a full trace for the librespot crate?

washed, 2025-02-04:
@tmh-alex yep, you can adjust individual crate/module log levels with the RUST_LOG env var in the service file.

tmh-alex, 2025-02-05:
Turned the box on in the morning with trace log level for the librespot crate enabled, placed tags on the read on occasion, and that's what I eventually got:

```
Feb 05 12:25:25 toniblaster drempelbox[760]: 2025-02-05T11:25:24.984800Z  INFO librespot_playback::player: Loading <Fünf kleine Fische> with Spotify URI <spotify:track:3LUEc1W82JkHDFudlPyaWW>
Feb 05 12:25:25 toniblaster drempelbox[760]: 2025-02-05T11:25:24.984934Z DEBUG librespot_audio::fetch: File c3f17d31c6835950bf62d9c3e844c6aa2c261dfe already in cache
Feb 05 12:25:25 toniblaster drempelbox[760]: 2025-02-05T11:25:24.985000Z  WARN librespot_playback::player: Unable to load key, continuing without decryption: Internal error { channel closed }
Feb 05 12:25:25 toniblaster drempelbox[760]: 2025-02-05T11:25:25.075861Z  WARN librespot_playback::player: Unable to read cached audio file: Symphonia Decoder Error: end of stream. Trying to download it.
Feb 05 12:25:25 toniblaster drempelbox[760]: 2025-02-05T11:25:25.077985Z DEBUG librespot_audio::fetch: Downloading file c3f17d31c6835950bf62d9c3e844c6aa2c261dfe
Feb 05 12:25:25 toniblaster drempelbox[760]: 2025-02-05T11:25:25.078175Z DEBUG librespot_core::http_client: Requesting https://spclient.wg.spotify.com:443/storage-resolve/files/audio/interactive/c3f17d31c6835950bf62d9c3e844c6aa2c261dfe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
Feb 05 12:25:25 toniblaster drempelbox[760]: 2025-02-05T11:25:25.110702Z TRACE librespot_core::cdn_url: Resolved CDN storage: CdnUrl {
Feb 05 12:25:25 toniblaster drempelbox[760]:     file_id: FileId(
Feb 05 12:25:25 toniblaster drempelbox[760]:         Ok(
Feb 05 12:25:25 toniblaster drempelbox[760]:             "c3f17d31c6835950bf62d9c3e844c6aa2c261dfe",
Feb 05 12:25:25 toniblaster drempelbox[760]:         ),
Feb 05 12:25:25 toniblaster drempelbox[760]:     ),
Feb 05 12:25:25 toniblaster drempelbox[760]:     urls: MaybeExpiringUrls(
Feb 05 12:25:25 toniblaster drempelbox[760]:         [
Feb 05 12:25:25 toniblaster drempelbox[760]:             MaybeExpiringUrl(
Feb 05 12:25:25 toniblaster drempelbox[760]:                 "https://audio-akp.spotifycdn.com/audio/c3f17d31c6835950bf62d9c3e844c6aa2c261dfe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",
Feb 05 12:25:25 toniblaster drempelbox[760]:                 Some(
Feb 05 12:25:25 toniblaster drempelbox[760]:                     Date(
Feb 05 12:25:25 toniblaster drempelbox[760]:                         2025-02-06 11:20:25.0 +00:00:00,
Feb 05 12:25:25 toniblaster drempelbox[760]:                     ),
Feb 05 12:25:25 toniblaster drempelbox[760]:                 ),
Feb 05 12:25:25 toniblaster drempelbox[760]:             ),
Feb 05 12:25:25 toniblaster drempelbox[760]:             MaybeExpiringUrl(
Feb 05 12:25:25 toniblaster drempelbox[760]:                 "https://audio4-fa.scdn.co/audio/c3f17d31c6835950bf62d9c3e844c6aa2c261dfe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",
Feb 05 12:25:25 toniblaster drempelbox[760]:                 Some(
Feb 05 12:25:25 toniblaster drempelbox[760]:                     Date(
Feb 05 12:25:25 toniblaster drempelbox[760]:                         2025-02-06 11:20:25.0 +00:00:00,
Feb 05 12:25:25 toniblaster drempelbox[760]:                     ),
Feb 05 12:25:25 toniblaster drempelbox[760]:                 ),
Feb 05 12:25:25 toniblaster drempelbox[760]:             ),
Feb 05 12:25:25 toniblaster drempelbox[760]:         ],
Feb 05 12:25:25 toniblaster drempelbox[760]:     ),
Feb 05 12:25:25 toniblaster drempelbox[760]: }
Feb 05 12:25:25 toniblaster drempelbox[760]: 2025-02-05T11:25:25.110860Z TRACE librespot_audio::fetch: Streaming from https://audio-akp.spotifycdn.com/audio/c3f17d31c6835950bf62d9c3e844c6aa2c261dfe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
Feb 05 12:25:25 toniblaster drempelbox[760]: 2025-02-05T11:25:25.157328Z  WARN librespot_playback::player: Unable to load key, continuing without decryption: Internal error { channel closed }
Feb 05 12:25:25 toniblaster drempelbox[760]: 2025-02-05T11:25:25.279691Z TRACE librespot_audio::fetch::receive: Time to first byte now estimated as: 121 ms
Feb 05 12:25:25 toniblaster drempelbox[760]: 2025-02-05T11:25:25.279962Z  WARN librespot_audio::fetch::receive: Throughput 1 kbps lower than minimum 8, setting to minimum
Feb 05 12:25:25 toniblaster drempelbox[760]: 2025-02-05T11:25:25.280001Z TRACE librespot_audio::fetch::receive: Throughput now estimated as: 8 kbps
Feb 05 12:25:25 toniblaster drempelbox[760]: 2025-02-05T11:25:25.333800Z TRACE librespot_audio::fetch::receive: Time to first byte now estimated as: 85 ms
Feb 05 12:25:25 toniblaster drempelbox[760]: 2025-02-05T11:25:25.375480Z TRACE librespot_audio::fetch::receive: Throughput now estimated as: 372 kbps
Feb 05 12:25:25 toniblaster drempelbox[760]: 2025-02-05T11:25:25.407149Z TRACE librespot_audio::fetch::receive: Time to first byte now estimated as: 48 ms
Feb 05 12:25:25 toniblaster drempelbox[760]: 2025-02-05T11:25:25.470073Z TRACE librespot_audio::fetch::receive: Throughput now estimated as: 546 kbps
Feb 05 12:25:25 toniblaster drempelbox[760]: 2025-02-05T11:25:25.499127Z TRACE librespot_audio::fetch::receive: Time to first byte now estimated as: 29 ms
Feb 05 12:25:25 toniblaster drempelbox[760]: 2025-02-05T11:25:25.549714Z TRACE librespot_audio::fetch::receive: Throughput now estimated as: 698 kbps
Feb 05 12:25:25 toniblaster drempelbox[760]: 2025-02-05T11:25:25.609127Z TRACE librespot_audio::fetch::receive: Throughput now estimated as: 924 kbps
Feb 05 12:25:25 toniblaster drempelbox[760]: 2025-02-05T11:25:25.631070Z TRACE librespot_audio::fetch::receive: Time to first byte now estimated as: 24 ms
Feb 05 12:25:25 toniblaster drempelbox[760]: 2025-02-05T11:25:25.767691Z TRACE librespot_audio::fetch::receive: Time to first byte now estimated as: 21 ms
Feb 05 12:25:25 toniblaster drempelbox[760]: 2025-02-05T11:25:25.801718Z TRACE librespot_audio::fetch::receive: Throughput now estimated as: 1084 kbps
Feb 05 12:25:26 toniblaster drempelbox[760]: 2025-02-05T11:25:26.773525Z TRACE librespot_audio::fetch::receive: Time to first byte now estimated as: 22 ms
Feb 05 12:25:26 toniblaster drempelbox[760]: 2025-02-05T11:25:26.830115Z TRACE librespot_audio::fetch::receive: Throughput now estimated as: 960 kbps
Feb 05 12:25:27 toniblaster drempelbox[760]: 2025-02-05T11:25:27.578631Z DEBUG librespot_audio::fetch: Downloading file c3f17d31c6835950bf62d9c3e844c6aa2c261dfe complete
Feb 05 12:25:27 toniblaster drempelbox[760]: 2025-02-05T11:25:27.579328Z ERROR librespot_playback::player: Unable to read audio file: Symphonia Decoder Error: end of stream
Feb 05 12:25:27 toniblaster drempelbox[760]: 2025-02-05T11:25:27.579612Z ERROR librespot_playback::player: Skipping to next track, unable to load track <SpotifyId("spotify:track:3LUEc1W82JkHDFudlPyaWW")>: ()
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
tmh-alex, 2025-02-10:
May be related to [this librespot issue](https://github.com/librespot-org/librespot/issues/1433) when playing 96 kbps files. Apparently some regression on the type definitions. Investigation and fix [here](https://github.com/librespot-org/librespot/pull/1434), however, hasn't made it into the main branch yet. Will wait if the next release will fix my issue.

tmh-alex, 2025-02-10:
Here's the logs from a failed session with the trace logging option on.

[journald_drempelbox_20250205_symphoniadecodererror.txt](https://github.com/user-attachments/files/18734458/journald_drempelbox_20250205_symphoniadecodererror.txt)

photovoltex, 2025-02-22:
> May be related to https://github.com/librespot-org/librespot/issues/1433 when playing 96 kbps files.

Just checked the log file, and this doesn't seem to be related to the 96 kbps issue.
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

But I saw the error recently on a [different issue](https://github.com/librespot-org/librespot/issues/1419#issuecomment-2672074708). Tho I think it's a separate issue from the issue commented on from what I see here, but that's just a guess so far.

tmh-alex, 2025-02-23:
@photovoltex Thank you for checking on our issue, very much appreciated! Unfortunately I'm now completely at a loss here, as the upstream issue you linked doesn't seem to be at work here either. I experienced a couple of freezes in the past 24 h, yet my router says it's been continuously connected to the internet for the past three days.

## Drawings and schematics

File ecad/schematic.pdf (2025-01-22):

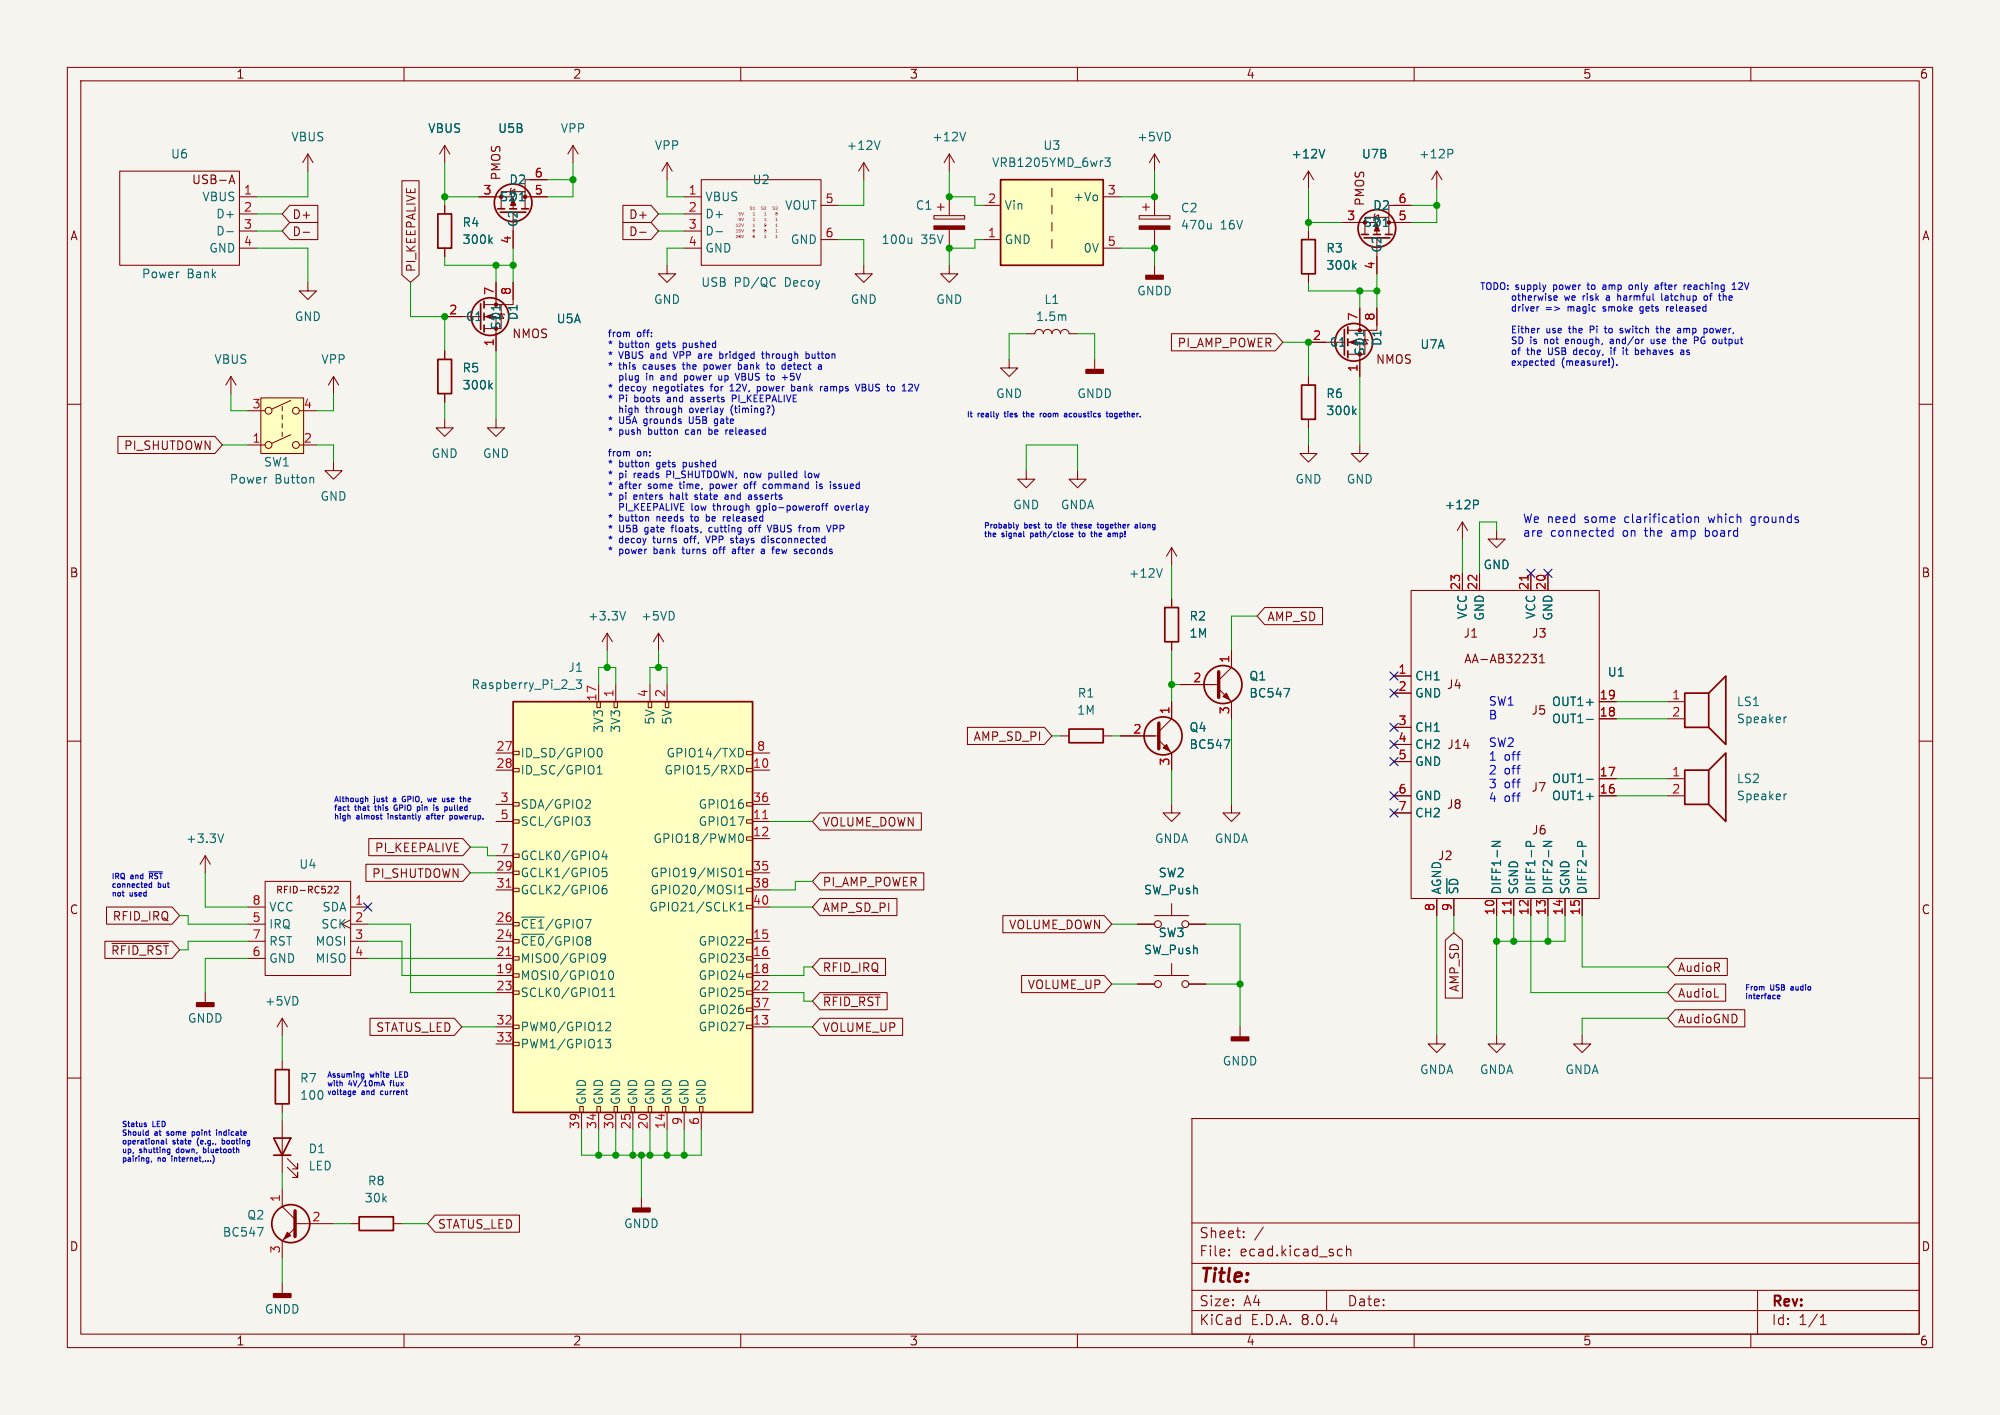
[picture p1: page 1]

from off: * button gets pushed

* this causes the power bank to detect a
plug in and power up VBUS to +5V
* Pi boots and asserts PI_KEEPALIVE

* push button can be released

from on: * button gets pushed

* pi reads PI_SHUTDOWN, now pulled low
* button needs to be released
* decoy turns off, VPP stays disconnected

fact that this GPIO pin is pulled

Id: 1/1 Title: File: ecad.kicad_sch Sheet: / SW2 SW_Push GNDD

Status LED
Should at some point indicate

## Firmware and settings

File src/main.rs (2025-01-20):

use std::time::Duration;

use tokio::sync::mpsc;
use tokio::task::JoinSet;
use tokio::time::sleep;
use tracing::error;

pub mod ndef;
pub mod ntag215;

pub mod file_player;
pub mod spotify_player;

pub mod server;
use crate::server::{start_server_task, AppState};

pub mod ntag;
use crate::ntag::start_ntag_reader_task;

pub mod player;
use crate::player::{start_player_task, PlayerRequestMessage};

pub mod tuple_windows;

pub mod amp;
use crate::amp::Amp;

pub mod shutdown;
use crate::shutdown::Shutdown;

pub mod button;
pub mod volume_buttons;
use crate::volume_buttons::VolumeButtons;

pub mod led;
use crate::led::Led;

#[tokio::main()]
async fn main() -> Result<(), Box<dyn std::error::Error>> {
    tracing_subscriber::fmt::init();

    let mut join_set = JoinSet::<()>::new();

    let amp = Amp::new(&mut join_set).await?;
    let amp_player = amp.clone();

    let led = Led::new(&mut join_set).await?;

    let _shutdown = Shutdown::new(&mut join_set).await?;

    let (sender, receiver) = mpsc::channel::<PlayerRequestMessage>(16);
    let app_state = AppState { sender, amp, led };

    let _volume_button = VolumeButtons::new(app_state.clone().sender)?;

    start_player_task(&mut join_set, receiver, amp_player).await?;
    start_ntag_reader_task(&mut join_set, app_state.clone()).await;
    start_server_task(&mut join_set, app_state.clone()).await;

    app_state.amp.power_on().await?;
    sleep(Duration::from_millis(250)).await;
    app_state.led.on().await?;

    while let Some(_res) = join_set.join_next().await {
        let err = _res.err().unwrap().to_string();
        error!(err, "Task finished unexpectedly!");
        // TODO: we should probably crash the app at this point
    }

    Ok(())
}

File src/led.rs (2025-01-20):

use std::sync::Arc;

use rppal::gpio::{Error, Gpio, OutputPin};
use tokio::{
    sync::{
        mpsc::{unbounded_channel, UnboundedSender},
        oneshot, Mutex,
    },
    task::JoinSet,
};
use tracing::{debug, error, warn};

pub enum LedControlMessage {
    On { responder: oneshot::Sender<()> },
    Off { responder: oneshot::Sender<()> },
}

#[derive(Clone)]
pub struct Led {
    sender: Arc<Mutex<UnboundedSender<LedControlMessage>>>,
}

impl Led {
    const LED_GPIO_PIN: u8 = 12;

    pub async fn new(join_set: &mut JoinSet<()>) -> Result<Self, Error> {
        let mut pin_led = Self::get_pin_led().ok();

        let (sender, mut receiver) = unbounded_channel::<LedControlMessage>();

        join_set.spawn(async move {
            loop {
                let message = receiver.recv().await;

                match message {
                    Some(message) => match message {
                        LedControlMessage::On { responder } => {
                            match &mut pin_led {
                                Some(pin_led) => pin_led.set_high(),
                                None => warn!("couldn't set amp LED to high, no pin_led"),
                            }
                            match responder.send(()) {
                                Ok(_) => {}
                                Err(_) => error!("error sending amp LED on message response"),
                            };
                        }
                        LedControlMessage::Off { responder } => {
                            match &mut pin_led {
                                Some(pin_led) => pin_led.set_low(),
                                None => warn!("couldn't set amp LED to low, no pin_led"),
                            }
                            match responder.send(()) {
                                Ok(_) => {}
                                Err(_) => error!("error sending amp LED off message response"),
                            };
                        }
                    },
                    None => error!("led channel closed"),
                };
            }
        });

        let sender = Arc::new(Mutex::new(sender));

        Ok(Led { sender })
    }

    fn get_pin_led() -> Result<OutputPin, Error> {
        let mut pin_led: OutputPin = Gpio::new()?.get(Led::LED_GPIO_PIN)?.into_output();
        pin_led.set_low();
        Ok(pin_led)
    }

    pub async fn on(&self) -> Result<(), tokio::sync::oneshot::error::RecvError> {
        let sender = self.sender.lock().await;
        let (response_sender, response_receiver) = oneshot::channel::<()>();
        match sender.send(LedControlMessage::On {
            responder: response_sender,
        }) {
            Ok(_) => debug!("submitted amp LED on request"),
            Err(e) => error!("error submitting amp LED on request: {e}"),
        };

        response_receiver.await
    }

    pub async fn off(&self) -> Result<(), tokio::sync::oneshot::error::RecvError> {
        let sender = self.sender.lock().await;
        let (response_sender, response_receiver) = oneshot::channel::<()>();
        match sender.send(LedControlMessage::Off {
            responder: response_sender,
        }) {
            Ok(_) => debug!("submitted amp LED off request"),
            Err(e) => error!("error submitting amp LED off request: {e}"),
        };

        response_receiver.await
    }
}

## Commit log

2023-09-24 first cut at ndef parser
2023-09-24 small fixes on ndef parser
    [main.rs, ntag215.rs]
2023-09-25 fix warnings in ntag215
    [ntag215.rs]
2023-10-15 run everything in threads, add spotify
2023-10-17 replace spotify_player with librespot
    [main.rs]
2023-10-21 add bom
2023-10-29 Welp, on arm with actions
2023-10-29 Revert "Welp, on arm with actions"
    This reverts commit a57d8a3a6787ca5611f0cbcfd86bd5fb027182c5.
2023-10-30 add schematic
    [ecad.kicad_pcb, ecad.kicad_sch]
2023-10-30 link schematic in readme
2023-10-30 update schematic
    [ecad.kicad_sch]
2023-10-30 fix amp gpio, add make targets
    [amp.rs]
2023-10-30 try to add schematic to readme
2023-10-31 pi softoff, new amp power control
    [ecad.kicad_sch]
2023-10-31 updated amp control, more notes
    [ecad.kicad_sch]
2023-10-31 simplify amp sd control, invert logic
    [amp.rs]
2023-11-10 Use specifier %u in service file to determine current user
2024-01-24 Power management 2 (#15)
    * refine power management
    * update readme
    * add PI shutdown input
    * add shutdown stub
    * shutdown wip
    * use service user wip
    * update power circuit description
    * update power management
    * added amp power switching
    * update schematic for amp power ctl
    * add amp power ctl
    * update readme for necessary groups for user
    * update UID in service file
    * add short after amp power up
    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
    [ecad.kicad_sch]
2024-02-12 Added buttons.rs
2024-02-15 Most basic volume buttons implementation (only info msgs, no volume change)
    This is only the very first attempt of implementing the volume buttons and
    far from complete. Despite being an almost 1:1 copy of the shutdown code,
    it was helpful typing it myself line by line and deal with the code
    analyzer.
    Also, I'm learning Vim with its myriad plugins that make it a full-fledged
    IDE as I go. Imagine an old, one legged man with a weight on his foot doing
    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
2024-02-16 Moved magic pin numbers to consts
2024-02-19 Debounce and react on properly pressed buttons
    Also fixes a pin number, been to lazy to move to separate commit.
2024-02-28 Created ButtonAction trait and moved volume actions into dedicated structs
    Hard nut to crack until I found
    https://blog.rust-lang.org/inside-rust/2022/11/17/async-fn-in-trait-nightly.html#runtime-type-erasure
2024-03-04 simplified button and volume buttons impl
2024-03-19 increase button poll frequency and debounce count
2024-09-29 Changed graphical pin order
    The graphical ordering in the datasheet with supplies being on the
    bottom and grounds on the top is stupid for schematics.
2024-09-29 Replaced step-down with DC/DC converter and added digital grounds
    [ecad.kicad_sch]
2025-01-17 Bump deps (#37)
    * add ARG default to silence docker warning
    * update deps within old versions
    * bump major versions
    * reduce log level on button logging
    * adjust for new MFRC/SPI drivers, added delays
    * workaround a compiler bug in GCC 9.4 amd64
    * just one more bump
    * reduce logging noise
    * remove the faaaaaake
    * fix RFID by downgrading MFRC522 driver
    * remove unused/reexported deps
    * don't log on timeout in rfid select loop
    * make RFID GPIO init simpler, add IRQ pin init
    ---------
    [ntag.rs, ntag215.rs]
2025-01-20 Status led (#38)
    * Added new LED module
    * Turning status LED on when program is ready
2025-01-22 Add volume buttons and led to schematic (#35)
    * Added volume buttons.
    * Added status LED circuit.
    * Some annotations.
    * Changed LED library element.
    * Replaced wrong +5V supply elements with +5VD
    * Updated schematics
    [ecad.kicad_sch]
